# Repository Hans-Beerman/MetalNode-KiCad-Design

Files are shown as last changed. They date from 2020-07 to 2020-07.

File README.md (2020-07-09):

**MetalNode MakerSpace Leiden**

The MetalNode is used to control the access to the Abene and the Stationary Large Grinder of the MakerSpace in Leiden

This repository contains the schematic drawings, made in KiCad for this node.

The PCB in this design is not meant to be used for a real printed circuit board, but is added to be used as a guideline for making the print by hand on a prefab PCB for experimental use.

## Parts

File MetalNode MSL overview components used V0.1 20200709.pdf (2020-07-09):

### MetalNode MakerSpace Leiden

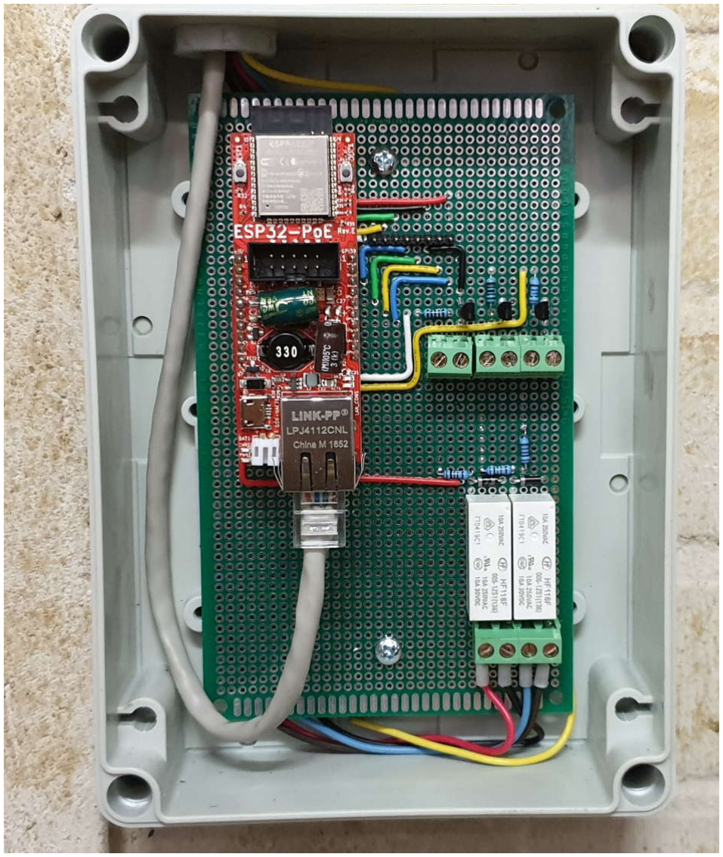
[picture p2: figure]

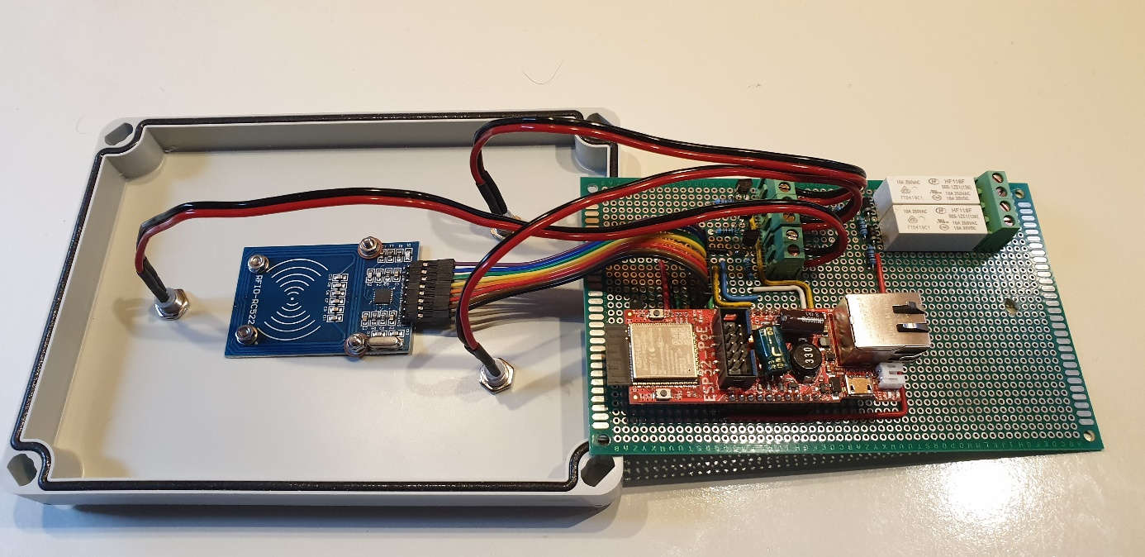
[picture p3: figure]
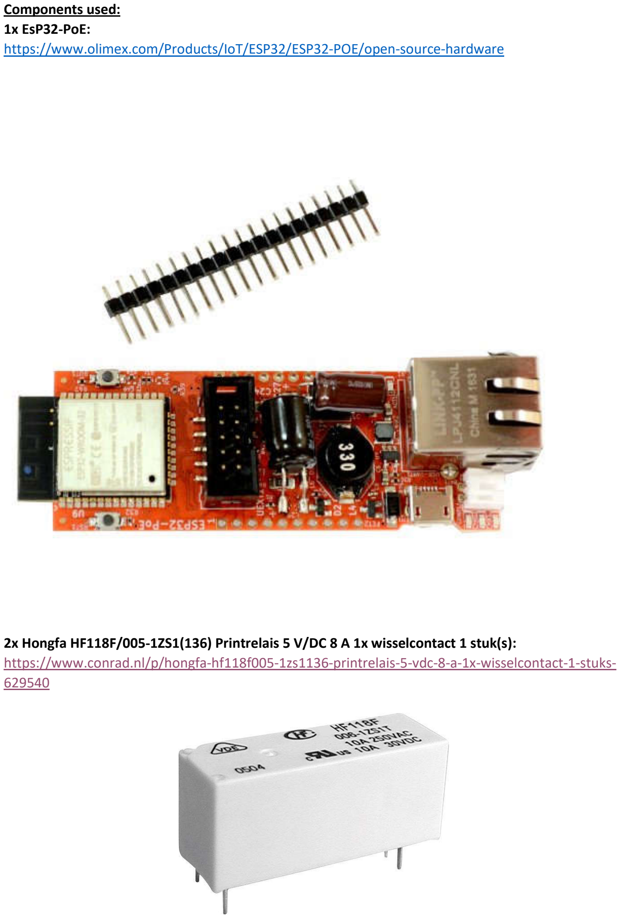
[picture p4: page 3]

Components used:
1x EsP32-PoE:
https://www.olimex.com/Products/IoT/ESP32/ESP32-POE/open-source-hardware

2x Hongfa HF118F/005-1ZS1(136) Printrelais 5 V/DC 8 A 1x wisselcontact 1 stuk(s): https://www.conrad.nl/p/hongfa-hf118f005-1zs1136-printrelais-5-vdc-8-a-1x-wisselcontact-1-stuks-629540

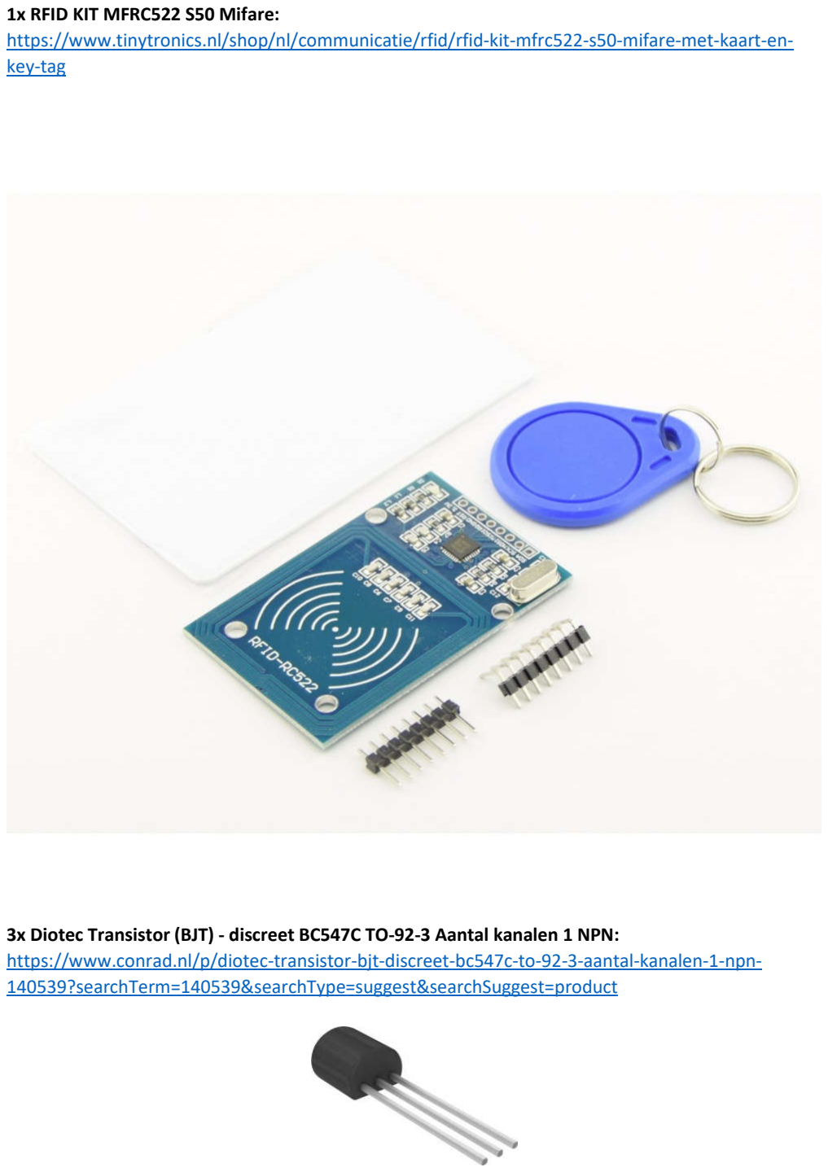
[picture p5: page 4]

1x RFID KIT MFRC522 S50 Mifare: https://www.tinytronics.nl/shop/nl/communicatie/rfid/rfid-kit-mfrc522-s50-mifare-met-kaart-enkey-tag

3x Diotec Transistor (BJT) - discreet BC547C TO-92-3 Aantal kanalen 1 NPN: https://www.conrad.nl/p/diotec-transistor-bjt-discreet-bc547c-to-92-3-aantal-kanalen-1-npn-140539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

2x Diode 1N4007:
https://www.tinytronics.nl/shop/nl/componenten/diode/diode-1n4007

6x 1KΩ weerstand:

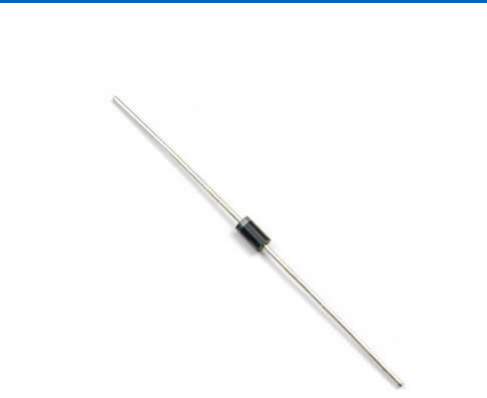
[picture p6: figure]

https://www.tinytronics.nl/shop/nl/componenten/weerstanden/1k%CF%89-weerstand

2x Rode LED - 5mm Diffuus: https://www.tinytronics.nl/shop/nl/verlichting/led-los/rode-led-5mm-diffuus

1x Groene LED - 5mm Diffuus:

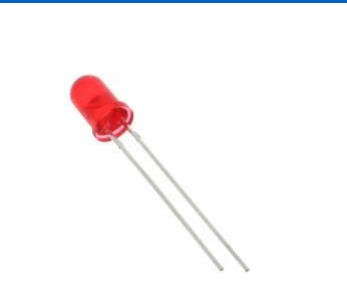
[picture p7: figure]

https://www.tinytronics.nl/shop/nl/verlichting/led-los/groene-led-5mm-diffuus

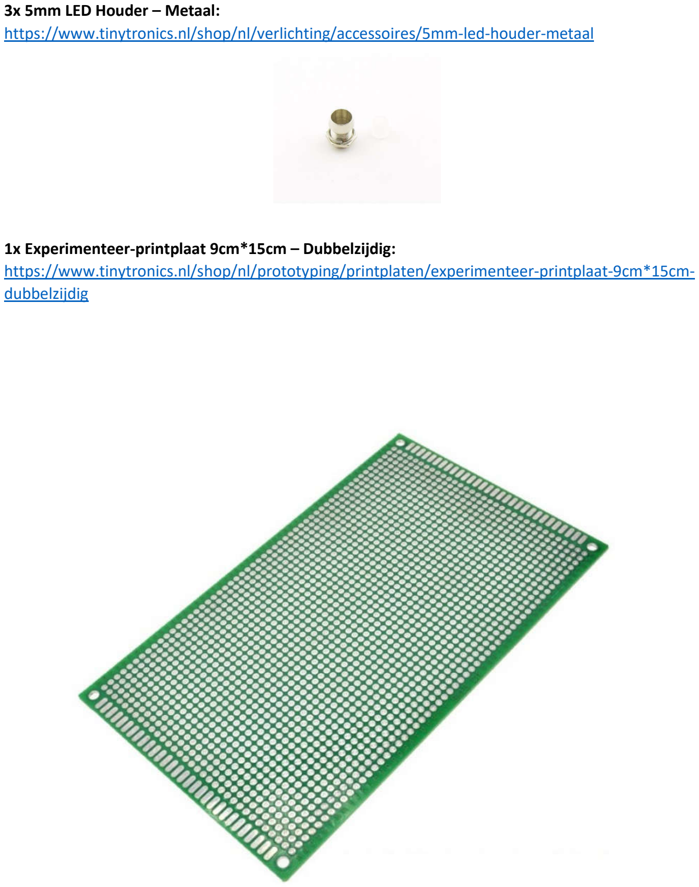
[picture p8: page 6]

3x 5mm LED Houder – Metaal: https://www.tinytronics.nl/shop/nl/verlichting/accessoires/5mm-led-houder-metaal

1x Experimenteer-printplaat 9cm*15cm – Dubbelzijdig: https://www.tinytronics.nl/shop/nl/prototyping/printplaten/experimenteer-printplaat-9cm*15cmdubbelzijdig

5x 2 Pin Schroef Terminal Block Connector 5.08mm Afstand: https://www.tinytronics.nl/shop/nl/connectoren/schroef-terminal/2-pin-schroef-terminal-blockconnector-5.08mm-afstand

2x 10 Pins header Female:

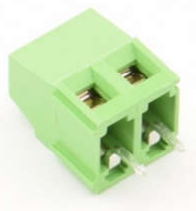
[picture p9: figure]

https://www.tinytronics.nl/shop/nl/connectoren/10-pins-header-female


1x DuPont Jumper draad Female-Female 10cm 10 draden: https://www.tinytronics.nl/shop/nl/kabels/prototype-draden/dupont-jumper-draad-female-female-10cm-10-draden


1x Spelsberg TK PS 1813-6F-M Installatiebehuizing 130 x 180 x 63 Polycarbonaat Lichtgrijs: https://www.conrad.nl/p/spelsberg-tk-ps-1813-6f-m-installatiebehuizing-130-x-180-x-63-polycarbonaat-lichtgrijs-1-stuks-1387570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


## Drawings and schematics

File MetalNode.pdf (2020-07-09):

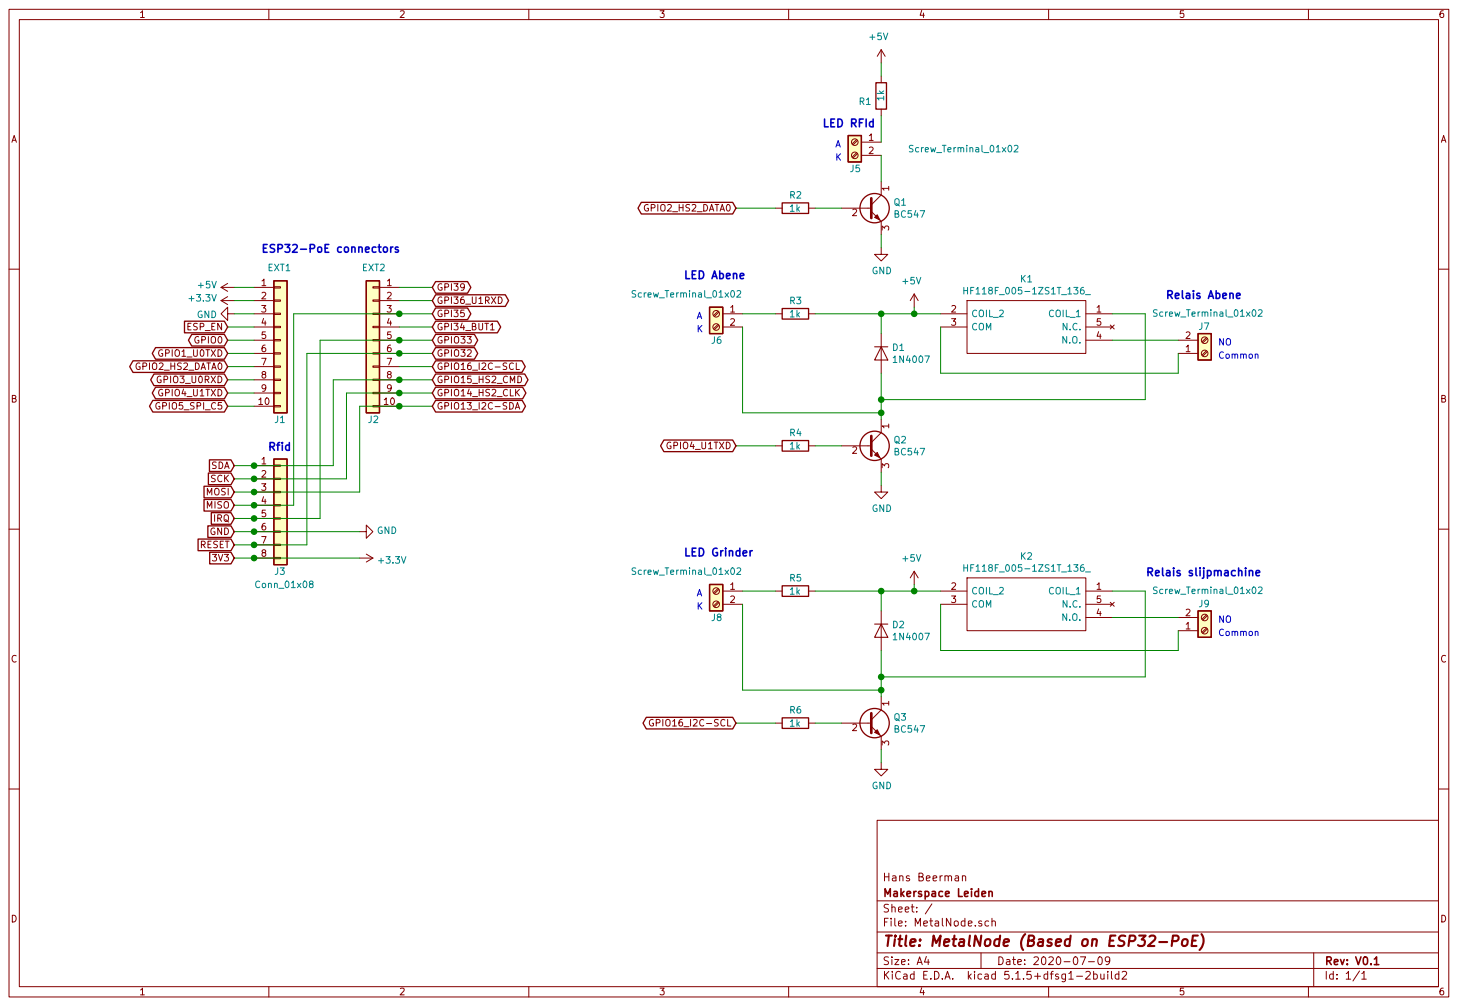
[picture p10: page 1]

Id: 1/1 Title: MetalNode (Based on ESP32-PoE) File: MetalNode.sch Sheet: / Makerspace Leiden Hans Beerman

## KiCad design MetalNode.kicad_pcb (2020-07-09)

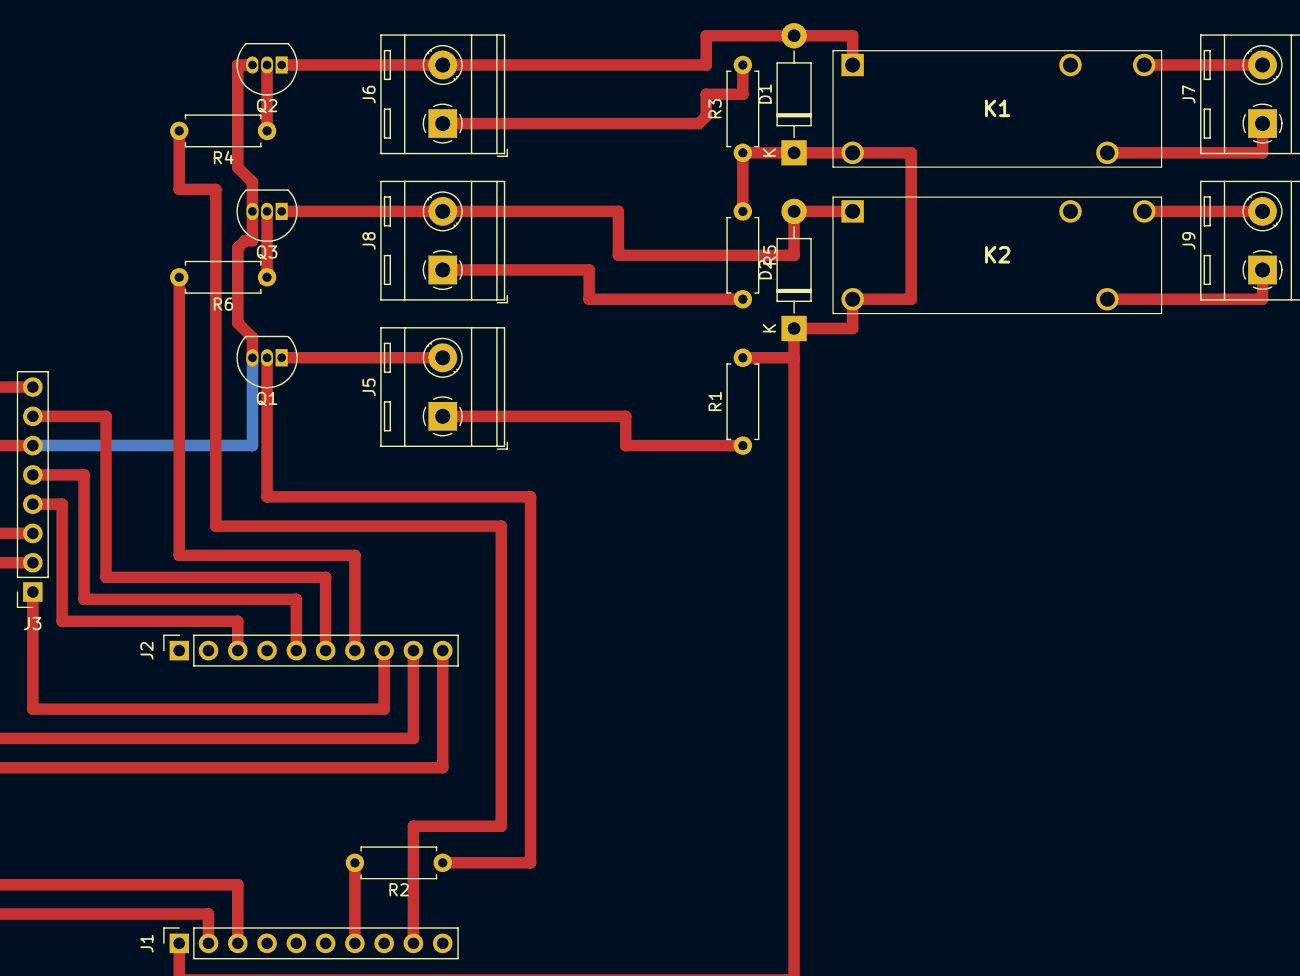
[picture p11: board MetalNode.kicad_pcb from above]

Board: 2 copper layers, 21 parts (0 on the bottom side), 25 nets.

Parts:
D1, D2: 1N4007; D_DO-41_SOD81_P10.16mm_Horizontal
J1: EXT1; PinSocket_1x10_P2.54mm_Vertical
J2: EXT2; PinSocket_1x10_P2.54mm_Vertical
J3: Conn_01x08; PinSocket_1x08_P2.54mm_Vertical
J5, J6, J7, J8, J9: Screw_Terminal_01x02; TerminalBlock_RND_205-00287_1x02_P5.08mm_Horizontal
K1, K2: HF118F_005-1ZS1T_136_; HF118F0051ZS1T136
Q1, Q2, Q3: BC547; TO-92_Inline
R1, R2, R3, R4, R5, R6: 1k; R_Axial_DIN0207_L6.3mm_D2.5mm_P7.62mm_Horizontal

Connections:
3V3: J1.2, J3.8
+5V: D1.1, D2.1, J1.1, K1.2, K2.2, R1.2, R3.1, R5.1
GND: J1.3, J3.6, Q1.3, Q2.3, Q3.3
GPI35: J2.3, J3.4
GPIO2_HS2_DATA0: J1.7, R2.2
GPIO4_U1TXD: J1.9, R4.2
GPIO13_I2C-SDA: J2.10, J3.3
GPIO14_HS2_CLK: J2.9, J3.2
GPIO15_HS2_CMD: J2.8, J3.1
GPIO16_I2C-SCL: J2.7, R6.2
GPIO32: J2.6, J3.7
GPIO33: J2.5, J3.5
unnamed: D1.2, J6.2, K1.1, Q2.1
unnamed: D2.2, J8.2, K2.1, Q3.1
unnamed: J5.1, R1.1
unnamed: J5.2, Q1.1
unnamed: J6.1, R3.2
unnamed: J7.1, K1.3
unnamed: J7.2, K1.4
unnamed: J8.1, R5.2
unnamed: J9.1, K2.3
unnamed: J9.2, K2.4
unnamed: Q1.2, R2.1
unnamed: Q2.2, R4.1
unnamed: Q3.2, R6.1
